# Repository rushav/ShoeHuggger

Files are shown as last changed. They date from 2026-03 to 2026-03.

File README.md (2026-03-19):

# ShoeHugger

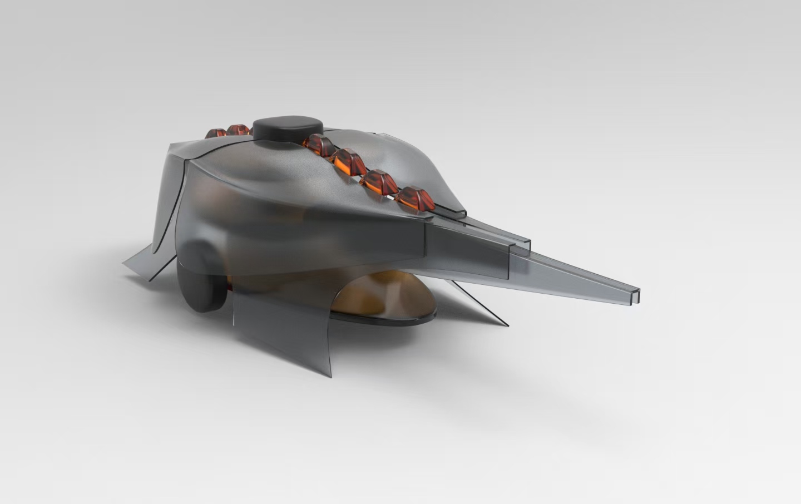
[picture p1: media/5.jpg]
ShoeHugger

More images in media folder

## About

ShoeHugger is a personal butler/pet robot built on a modified TurtleBot3 Waffle platform for TECHIN 516 at UW GIX (Winter 2025). It uses YOLOv8 pose estimation to detect and follow people by tracking ankle keypoints, features motorized wings that flap based on proximity, and avoids obstacles using LiDAR reactive avoidance.

### Demo Video
<!-- PLACEHOLDER: Add link to demo video -->
[Watch the demo video](https://youtu.be/eQ_k0fX2IQM)

## Features

- **Person Following**: Detects feet using YOLOv8n-pose ankle keypoints and follows the locked target
- **Two Modes**:
  - **Annoy Mode**: Aggressively chases person, wings flap faster as it gets closer
  - **Follow Mode**: Calmly follows from a distance, wings flap gently when stopped near person
- **Search Behavior**: Spins in place to find a new target when person is lost
- **Target Locking**: Locks onto one person's feet and ignores others using proximity + size filtering
- **Obstacle Avoidance**: Reactive LiDAR-based avoidance — slows/stops/steers around obstacles
- **Wing Mechanism**: 3rd DYNAMIXEL motor drives symmetric wings with variable-speed flapping
- **Control UI**: Tkinter GUI with mode switching, teleop, and emergency stop
- **SLAM Visualization**: Real-time map building in RViz alongside robot model
- **Auto-Start**: Pi bringup runs on boot via systemd — just power on and go

## Hardware

- TurtleBot3 Waffle (OpenCR + Raspberry Pi 4)
- 3rd DYNAMIXEL XL430 motor (ID 3) for wing mechanism
- TRAUSI 1080p USB webcam (rear-facing)
- LDS-01 LiDAR
- Custom 3D-printed chassis and wings (designed in SolidWorks)

## Team Contributions

| Member | Contributions |
|---|---|
| **Rushav** | Camera integration, person follower code (YOLO pose estimation, control logic, obstacle avoidance), custom bringup node, Pi systemd setup, UI, system integration |
| **Eason** | Robot 3D model design (SolidWorks), URDF creation and export, RViz visualization setup |
| **Phoenix** | Subscriber/publisher node architecture, ROS2 communication design |

## Architecture

```
+---------------------+     WiFi (ROS2 DDS)     +----------------------+
|   Raspberry Pi 4    |<------------------------>|   Laptop (Docker)    |
|                     |     ROS_DOMAIN_ID=117    |                      |
|alienbot_bringup.py|                          | person_follower.py   |
|  +- /cmd_vel (sub)  |                          |  +- /cmd_vel (pub)   |
|  +- /joint_states   |                          |  +- /wing_flap_speed |
|  +- /tf (odom->base)|                          |  +- /follower_image  |
|  +- /imu            |                          |                      |
|  +- /odom           |                          | alienbot_ui.py     |
|  +- /wing_flap_speed|                          | teleop_hold.py       |
|                     |                          | rviz2 + slam_toolbox |
| usb_cam_node        |                          +----------------------+
|  +- /image_raw/*    |
|                     |
| hlds_laser_publisher|
|  +- /scan           |
+---------------------+
```

## Setup Instructions

### Prerequisites
- Docker and VS Code with Dev Containers extension
- ROS2 Humble (installed in container)
- TurtleBot3 Waffle with OpenCR board flashed with GIX firmware

### 1. Clone the repository
```bash
git clone https://github.com/YOUR_USERNAME/alienbot.git
cd alienbot
```

### 2. Open in Dev Container
Open the folder in VS Code and select "Reopen in Container". The Dockerfile installs all dependencies automatically.

### 3. Build the workspace
```bash
cd ~/turtlebot4_ws
colcon build --symlink-install
source install/setup.bash
```

### 4. Set up the Raspberry Pi
Copy the Pi files and enable auto-start:
```bash
scp pi/alienbot_bringup.py ubuntu@<PI_IP>:~/alienbot_bringup.py
scp pi/start_alienbot.sh ubuntu@<PI_IP>:~/start_alienbot.sh
scp pi/alienbot.service ubuntu@<PI_IP>:~/alienbot.service
ssh ubuntu@<PI_IP>
chmod +x ~/start_alienbot.sh
sudo cp ~/alienbot.service /etc/systemd/system/
sudo systemctl daemon-reload
sudo systemctl enable alienbot
sudo systemctl start alienbot
```

Pi dependencies:
```bash
pip3 install dynamixel-sdk --break-system-packages
sudo apt install ros-humble-compressed-image-transport
```

### 5. Install OpenCR Firmware
Flash the modified GIX firmware using Arduino IDE. See `firmware/README.md` for details.

## Usage

### One-Command Launch (Laptop)
```bash
./launch/launch_alienbot.sh
```
This opens the control UI and RViz with SLAM. Use the UI buttons or keyboard shortcuts:

| Button | Key | Mode |
|---|-----|---|
| TELEOP | 1 | Manual arrow-key control |
| ANNOY | 2 | Aggressive person following + flapping |
| FOLLOW | 3 | Calm follow from distance |
| STOP ALL | 4 / Space / Esc | Emergency stop all motors |

### Manual Commands
```bash
# Test wheels
ros2 topic pub /cmd_vel geometry_msgs/msg/Twist "{linear: {x: 0.1}}" -r 10

# Test wing position
ros2 topic pub --once /wing_command std_msgs/msg/Float64 "{data: 0.5}"

# Test wing flapping
ros2 topic pub --once /wing_flap_speed std_msgs/msg/Float64 "{data: 0.5}"

# Stop flapping
ros2 topic pub --once /wing_flap_speed std_msgs/msg/Float64 "{data: 0.0}"
```

## License

This project is licensed under the Apache License 2.0 — see [LICENSE](LICENSE) for details.

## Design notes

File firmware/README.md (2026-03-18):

# OpenCR Firmware Modifications

## Overview

AlienBot uses a modified version of the GIX OpenCR firmware that adds support for a 3rd DYNAMIXEL motor (ID 3) used to drive the wing mechanism.

## Source Repository

The firmware is based on the `t516_OpenCR` repository provided for TECHIN 516.

## Configuration

In `t516_OpenCR.ino`, select the robot model:
```cpp
#define MODEL GIX_Waffle
```

## Key Modifications

### Velocity Limit
- `LIMIT_X_MAX_VELOCITY` increased from **337** to **500** to allow faster driving

### Wheel Separation
- Modified from **0.287 m** to **0.1552 m** to match the actual wheel-to-wheel distance of the custom chassis

### GIX Motor Driver (Wing Motor — DYNAMIXEL ID 3)
The GIX motor driver firmware extension reads and writes to DYNAMIXEL ID 3 using these control table addresses:

| Address | Description |
|---|---|
| 346 | Wing command input |
| 348-382 | Motor control registers |

The wing motor accepts:
- **Position commands** via `/wing_command` (Float64, 0.0–1.0 normalized)
- **Flap speed commands** via `/wing_flap_speed` (Float64, 0.0–1.0; 0.0 = stop flapping)

The bringup node on the Pi translates these ROS topics into DYNAMIXEL SDK writes.

## Flashing

1. Open `t516_OpenCR.ino` in Arduino IDE
2. Select board: **OpenCR**
3. Connect OpenCR via USB
4. Upload firmware
5. Verify by checking that all three motors respond (IDs 1, 2, 3)

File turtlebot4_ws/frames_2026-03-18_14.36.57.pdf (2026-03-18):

view_frames Result

Recorded at time: 1773869817.2450194

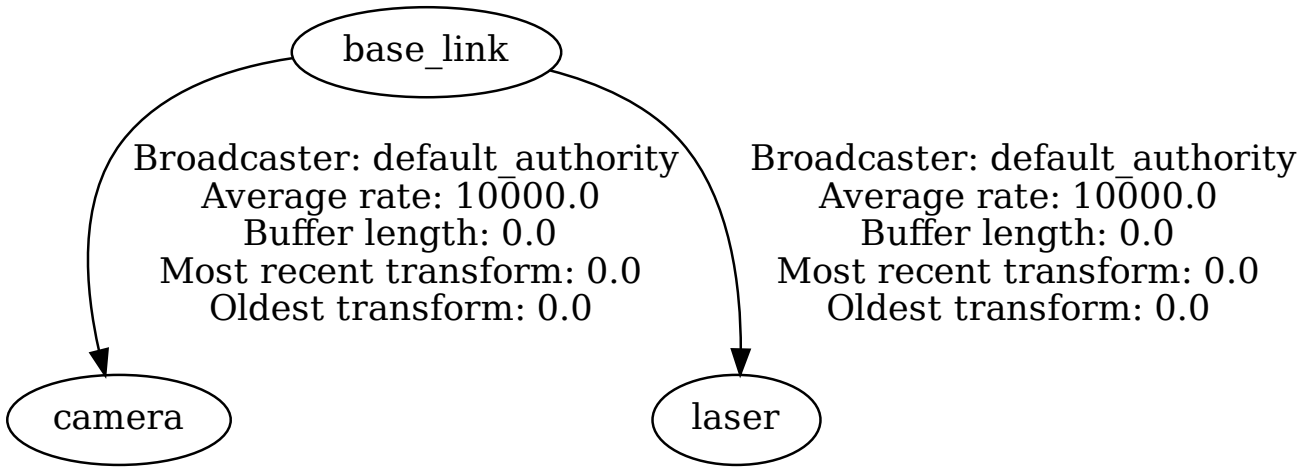
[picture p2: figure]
base_link; camera; Broadcaster: default_authority Average rate: 10000.0 Buffer length: 0.0 Most recent transform: 0.0 Oldest transform: 0.0; laser

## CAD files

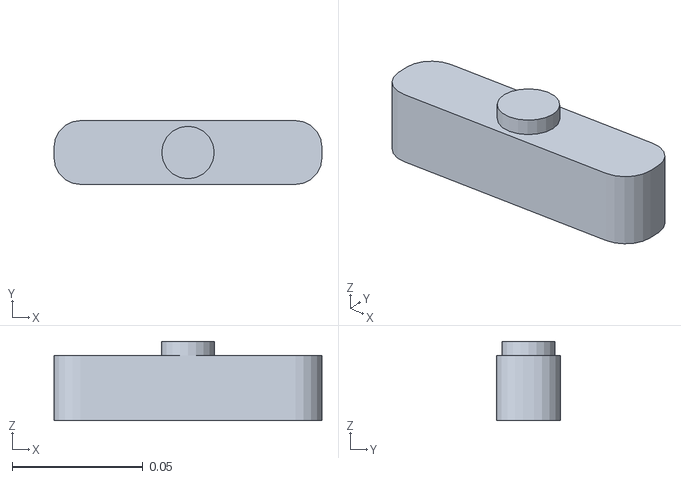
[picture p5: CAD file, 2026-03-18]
description/stls/camera.STL
0.103 x 0.0244 x 0.0302

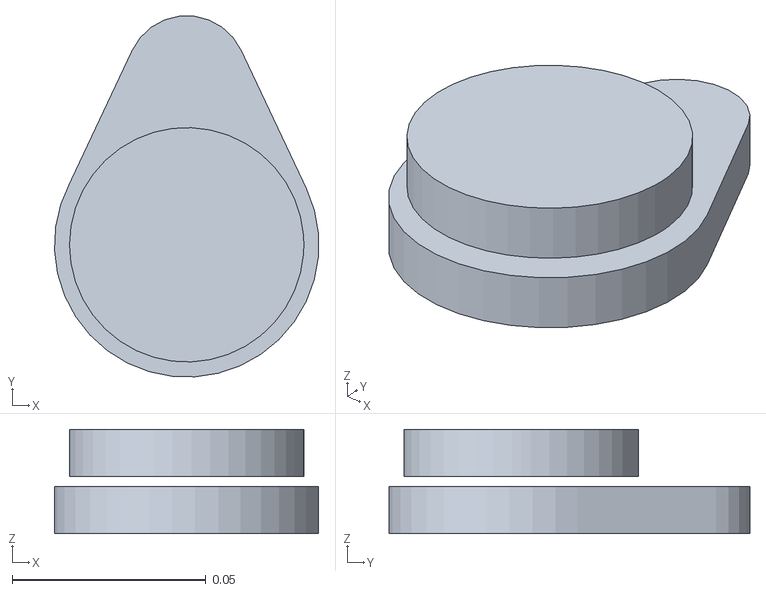
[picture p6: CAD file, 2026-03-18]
turtlebot4_ws/src/alienbot_description/stls/lidar.STL
0.068 x 0.093 x 0.0269

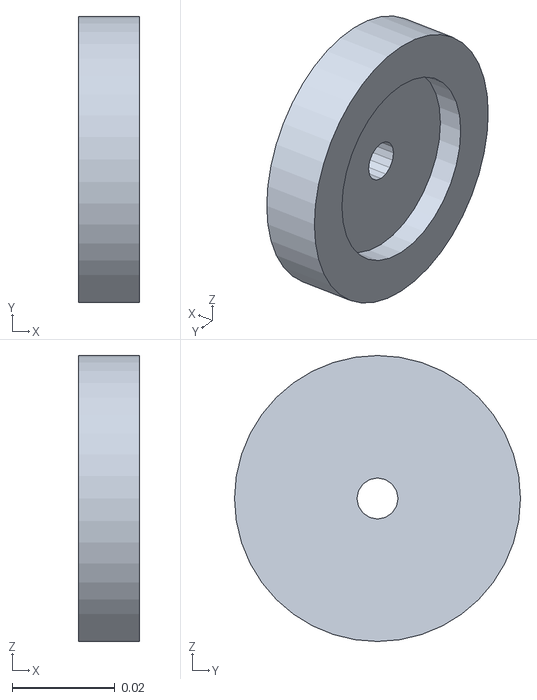
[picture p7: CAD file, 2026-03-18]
description/stls/wheel_right.STL
0.0119 x 0.0558 x 0.0558

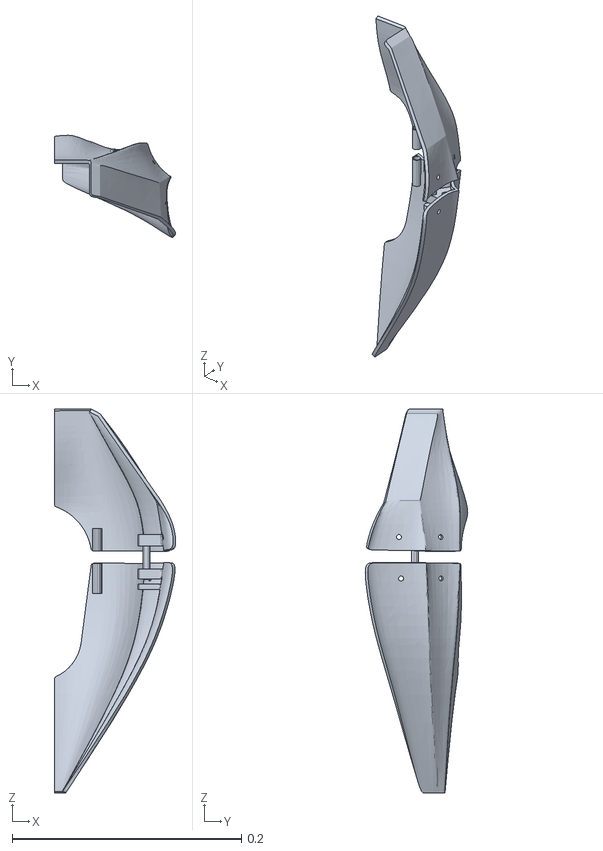
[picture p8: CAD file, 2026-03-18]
turtlebot4_ws/src/alienbot_description/stls/wing_left.STL
0.106 x 0.0894 x 0.335

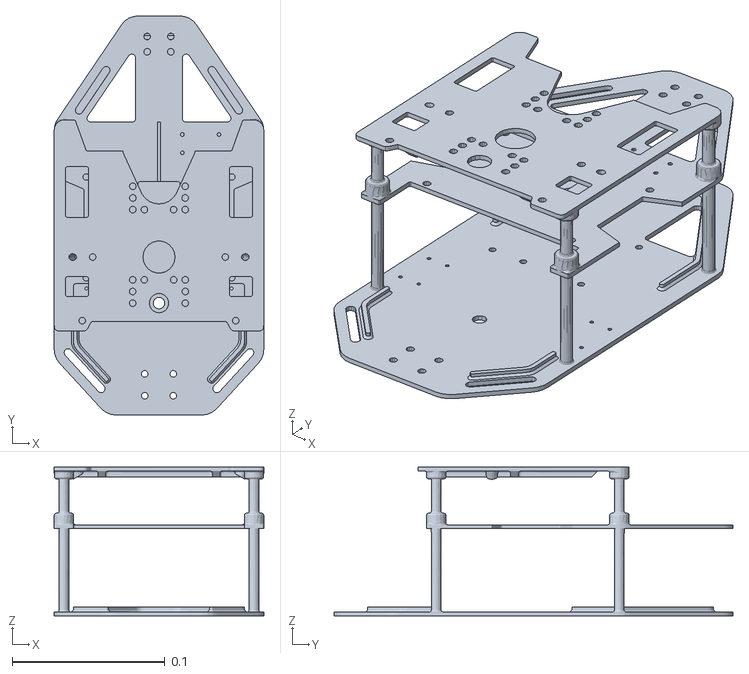
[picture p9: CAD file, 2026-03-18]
description/stls/base_link.STL
0.137 x 0.261 x 0.0972

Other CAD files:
description/stls/wing_right.STL
description/stls/wheel_left.STL
turtlebot4_ws/src/alienbot_description/stls/wheel_left.STL
turtlebot4_ws/src/alienbot_description/stls/wing_right.STL

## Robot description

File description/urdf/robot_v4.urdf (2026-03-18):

<?xml version="1.0" encoding="utf-8"?>
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
<robot name="robot_v4">
  <link name="base_link">
    <inertial>
      <origin xyz="5.19808910696973E-06 0.0437851037954019 -0.0153253924126023" rpy="0 0 0" />
      <mass value="0.174534133721049" />
      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
    </inertial>
    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
  </link>
  <link name="wheel_left">
    <inertial>
      <origin xyz="0.00514407681200836 8.17349660175992E-14 3.4527242176452E-13" rpy="0 0 0" />
      <mass value="0.0230128273536347" />
      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
    </inertial>
    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
  </link>
  <joint name="wheel_left_joint" type="continuous">
    <origin xyz="0.0725550532863032 0.0249218786292363 -0.0402038669112" rpy="1.5707963267949 0 0" />
    <parent link="base_link" />
    <child link="wheel_left" />
    <axis xyz="1 0 0" />
  </joint>
  <link name="wheel_right">
    <inertial>
      <origin xyz="-0.00514407681092399 -1.85615411929518E-16 -5.59760571228196E-14" rpy="0 0 0" />
      <mass value="0.0230128273536347" />
      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
    </inertial>
    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
  </link>
  <joint name="wheel_right_joint" type="continuous">
    <origin xyz="-0.0725550532790476 0.0249218786307316 -0.0402038669083703" rpy="1.5707963267949 0 0" />
    <parent link="base_link" />
    <child link="wheel_right" />
    <axis xyz="1 0 0" />
  </joint>
  <link name="laser">
    <inertial>
      <origin xyz="1.12248706154588E-05 0.0070553880342903 -0.000411928460549202" rpy="0 0 0" />
      <mass value="0.0906117336671421" />
      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
    </inertial>
    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
  </link>
  <joint name="laser_joint" type="fixed">
    <origin xyz="0 0.0155312690459461 0.055853305909985" rpy="0 0 0" />
    <parent link="base_link" />
    <child link="laser" />
    <axis xyz="0 0 0" />
  </joint>
  <link name="camera">
    <inertial>
      <origin xyz="3.46944695195361E-17 -0.000483315503227374 -0.0120319760925751" rpy="0 0 0" />
      <mass value="0.0618368133993102" />
      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
    </inertial>
    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
  </link>
  <joint name="camera_joint" type="fixed">
    <origin xyz="0 -0.102735934689195 0.0173275485336867" rpy="1.5707963267949 0 0" />
    <parent link="base_link" />
    <child link="camera" />
    <axis xyz="0 0 0" />
  </joint>
  <link name="wing_left">
    <inertial>
      <origin xyz="0.0202267783404892 -0.0171927414394959 -0.0447062400052274" rpy="0 0 0" />
      <mass value="0.11060024558919" />
      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
    </inertial>
    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
  </link>
  <joint name="wing_left_joint" type="continuous">
    <origin xyz="0.051772 0 0.048599" rpy="1.5708 0 0" />
    <parent link="base_link" />
    <child link="wing_left" />
    <axis xyz="0 0 1" />
  </joint>
  <link name="wing_right">
    <inertial>
      <origin xyz="-0.0202320893781205 -0.0171966751818292 -0.044652227528606" rpy="0 0 0" />
      <mass value="0.110625066259541" />
      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
    </inertial>
    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
  </link>
  <joint name="wing_right_joint" type="continuous">
    <origin xyz="-0.051772 0 0.048599" rpy="1.5708 0 0" />
    <parent link="base_link" />
    <child link="wing_right" />
    <axis xyz="0 0 1" />
  </joint>
</robot>

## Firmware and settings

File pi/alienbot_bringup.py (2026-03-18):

#!/usr/bin/env python3
"""
AlienBot Bringup Node — Raspberry Pi
=====================================
Custom replacement for turtlebot3_node that runs on the Raspberry Pi.
Communicates with the OpenCR board via DynamixelSDK to control:
  - Wheel motors (DYNAMIXEL ID 1, ID 2)
  - Wing motor (DYNAMIXEL ID 3)

Publishes:
    /odom (nav_msgs/Odometry) — wheel odometry
    /tf (odom → base_link transform)
    /imu (sensor_msgs/Imu) — IMU data from OpenCR
    /joint_states (sensor_msgs/JointState) — wheel + wing joint positions

Subscribes:
    /cmd_vel (geometry_msgs/Twist) — velocity commands for wheels
    /wing_flap_speed (std_msgs/Float64) — wing flap speed (0.0–1.0)
    /wing_command (std_msgs/Float64) — direct wing position (0.0–1.0)

This node reads motor positions and IMU data from OpenCR at ~30 Hz,
computes odometry, and publishes all sensor data to ROS2 topics.

Requires:
    pip3 install dynamixel-sdk

Usage:
    python3 alienbot_bringup.py
    OR via systemd (see alienbot.service)
"""

import math
import signal
import struct
import sys
import threading
import time

import rclpy
from rclpy.node import Node
from rclpy.qos import QoSProfile, ReliabilityPolicy
from geometry_msgs.msg import Twist, TransformStamped, Quaternion
from nav_msgs.msg import Odometry
from sensor_msgs.msg import Imu, JointState
from std_msgs.msg import Float64
from tf2_ros import TransformBroadcaster

from dynamixel_sdk import PortHandler, PacketHandler

# ── Hardware Configuration ────────────────────────────────────────────────────
DEVICE_PORT       = '/dev/ttyACM0'
BAUDRATE          = 1000000
PROTOCOL_VERSION  = 2.0

# DYNAMIXEL motor IDs
MOTOR_ID_LEFT     = 1    # left wheel
MOTOR_ID_RIGHT    = 2    # right wheel
MOTOR_ID_WING     = 3    # wing mechanism

# Robot physical parameters
WHEEL_RADIUS      = 0.033   # meters
WHEEL_SEPARATION  = 0.1552  # meters (modified from stock 0.287)

# OpenCR control table addresses for reading sensor data
ADDR_PRESENT_POSITION = 132   # 4 bytes
ADDR_PRESENT_VELOCITY = 128   # 4 bytes

# Wing motor control
ADDR_GOAL_POSITION    = 116   # 4 bytes
WING_MIN_POS          = 1024  # ~90° range of motion
WING_MAX_POS          = 3072
WING_CENTER_POS       = 2048

# GIX motor driver addresses for wing via OpenCR
ADDR_GIX_WING_CMD     = 346  # wing command register

# ── Timing ────────────────────────────────────────────────────────────────────
CONTROL_RATE_HZ   = 30    # main control loop frequency
CMD_VEL_TIMEOUT   = 1.0   # seconds — stop if no cmd_vel received
# ─────────────────────────────────────────────────────────────────────────────


class AlienBotBringup(Node):
    """ROS2 bringup node for AlienBot hardware on Raspberry Pi."""

    def __init__(self) -> None:
        super().__init__('alienbot_bringup')

        # ── DynamixelSDK setup ────────────────────────────────────────────
        self.port_handler = PortHandler(DEVICE_PORT)
        self.packet_handler = PacketHandler(PROTOCOL_VERSION)

        if not self.port_handler.openPort():
            self.get_logger().fatal(f'Failed to open port {DEVICE_PORT}')
            sys.exit(1)
        if not self.port_handler.setBaudRate(BAUDRATE):
            self.get_logger().fatal(f'Failed to set baudrate {BAUDRATE}')
            sys.exit(1)

        self.get_logger().info(
            f'Connected to OpenCR on {DEVICE_PORT} at {BAUDRATE} baud')

        # ── Publishers ────────────────────────────────────────────────────
        self.odom_pub = self.create_publisher(Odometry, '/odom', 10)
        self.imu_pub = self.create_publisher(Imu, '/imu', 10)
        self.joint_pub = self.create_publisher(JointState, '/joint_states', 10)
        self.tf_broadcaster = TransformBroadcaster(self)

        # ── Subscribers ───────────────────────────────────────────────────
        self.cmd_vel_sub = self.create_subscription(
            Twist, '/cmd_vel', self.cmd_vel_callback, 10)
        self.wing_flap_sub = self.create_subscription(
            Float64, '/wing_flap_speed', self.wing_flap_callback, 10)
        self.wing_cmd_sub = self.create_subscription(
            Float64, '/wing_command', self.wing_cmd_callback, 10)

        # ── State ─────────────────────────────────────────────────────────
        self.target_linear = 0.0
        self.target_angular = 0.0
        self.last_cmd_time = time.time()

        # Odometry state
        self.odom_x = 0.0
        self.odom_y = 0.0
        self.odom_theta = 0.0
        self.prev_left_pos = None
        self.prev_right_pos = None
        self.prev_time = time.time()

        # Wing flap state
        self.wing_flap_speed = 0.0
        self.wing_flap_phase = 0.0
        self.wing_position = 0.5  # normalized 0.0–1.0

        self.running = True

        # ── Main control timer ────────────────────────────────────────────
        self.control_timer = self.create_timer(
            1.0 / CONTROL_RATE_HZ, self.control_loop)

        self.get_logger().info('AlienBot bringup node started!')

    # ── Callbacks ─────────────────────────────────────────────────────────

    def cmd_vel_callback(self, msg: Twist) -> None:
        """Receive velocity commands for wheels."""
        self.target_linear = msg.linear.x
        self.target_angular = msg.angular.z
        self.last_cmd_time = time.time()

    def wing_flap_callback(self, msg: Float64) -> None:
        """Set wing flap speed (0.0 = stop, 1.0 = max speed)."""
        self.wing_flap_speed = max(0.0, min(1.0, msg.data))
        if self.wing_flap_speed == 0.0:
            self.wing_flap_phase = 0.0
        self.get_logger().info(f'Wing flap speed: {self.wing_flap_speed:.2f}')

    def wing_cmd_callback(self, msg: Float64) -> None:
        """Set wing position directly (0.0–1.0 normalized)."""
        self.wing_position = max(0.0, min(1.0, msg.data))
        self.wing_flap_speed = 0.0  # direct position overrides flapping

    # ── Main control loop ─────────────────────────────────────────────────

    def control_loop(self) -> None:
        """Read sensors, compute odometry, send motor commands at fixed rate."""
        if not self.running:
            return

        now = time.time()
        dt = now - self.prev_time
        self.prev_time = now

        # Watchdog — stop if no cmd_vel received recently
        if now - self.last_cmd_time > CMD_VEL_TIMEOUT:
            self.target_linear = 0.0
            self.target_angular = 0.0

        # Send wheel velocity commands
        self._send_wheel_velocities(self.target_linear, self.target_angular)

        # Update wing flapping
        self._update_wing(dt)

        # Publish odometry and TF
        self._publish_odometry(dt)

        # Publish joint states
        self._publish_joint_states()

    # ── Motor control ─────────────────────────────────────────────────────

    def _send_wheel_velocities(self, linear: float, angular: float) -> None:
        """Convert (linear, angular) to individual wheel velocities and send."""
        left_vel = linear - angular * WHEEL_SEPARATION / 2.0
        right_vel = linear + angular * WHEEL_SEPARATION / 2.0

        # Convert m/s to DYNAMIXEL velocity units
        left_raw = int(left_vel / (WHEEL_RADIUS * 2 * math.pi) * 60 / 0.229)
        right_raw = int(right_vel / (WHEEL_RADIUS * 2 * math.pi) * 60 / 0.229)

        try:
            self.packet_handler.write4ByteTxOnly(
                self.port_handler, MOTOR_ID_LEFT, ADDR_PRESENT_VELOCITY, left_raw)
            self.packet_handler.write4ByteTxOnly(
                self.port_handler, MOTOR_ID_RIGHT, ADDR_PRESENT_VELOCITY, right_raw)
        except Exception as e:
            self.get_logger().warning(f'Wheel write error: {e}')

    def _update_wing(self, dt: float) -> None:
        """Update wing position based on flap speed or direct command."""
        if self.wing_flap_speed > 0.0:
            # Sinusoidal flapping
            freq = self.wing_flap_speed * 3.0  # max ~3 Hz flap
            self.wing_flap_phase += freq * dt * 2 * math.pi
            position = 0.5 + 0.4 * math.sin(self.wing_flap_phase)
        else:
            position = self.wing_position

        # Convert to DYNAMIXEL position
        goal_pos = int(WING_MIN_POS + position * (WING_MAX_POS - WING_MIN_POS))
        try:
            self.packet_handler.write4ByteTxOnly(
                self.port_handler, MOTOR_ID_WING, ADDR_GOAL_POSITION, goal_pos)
        except Exception as e:
            self.get_logger().warning(f'Wing write error: {e}')

    # ── Odometry ──────────────────────────────────────────────────────────

    def _publish_odometry(self, dt: float) -> None:
        """Compute and publish wheel odometry + TF."""
        stamp = self.get_clock().now().to_msg()

        # Publish odometry message
        odom_msg = Odometry()
        odom_msg.header.stamp = stamp
        odom_msg.header.frame_id = 'odom'
        odom_msg.child_frame_id = 'base_link'
        odom_msg.pose.pose.position.x = self.odom_x
        odom_msg.pose.pose.position.y = self.odom_y
        odom_msg.pose.pose.orientation = self._yaw_to_quaternion(self.odom_theta)
        odom_msg.twist.twist.linear.x = self.target_linear
        odom_msg.twist.twist.angular.z = self.target_angular
        self.odom_pub.publish(odom_msg)

        # Broadcast TF: odom → base_link
        tf_msg = TransformStamped()
        tf_msg.header.stamp = stamp
        tf_msg.header.frame_id = 'odom'
        tf_msg.child_frame_id = 'base_link'
        tf_msg.transform.translation.x = self.odom_x
        tf_msg.transform.translation.y = self.odom_y
        q = self._yaw_to_quaternion(self.odom_theta)
        tf_msg.transform.rotation = q
        self.tf_broadcaster.sendTransform(tf_msg)

    def _publish_joint_states(self) -> None:
        """Publish joint states for URDF visualization."""
        js = JointState()
        js.header.stamp = self.get_clock().now().to_msg()
        js.name = ['wheel_left_joint', 'wheel_right_joint',
                    'wing_left_joint', 'wing_right_joint']
        js.position = [0.0, 0.0, 0.0, 0.0]
        js.velocity = []
        js.effort = []
        self.joint_pub.publish(js)

    @staticmethod
    def _yaw_to_quaternion(yaw: float) -> Quaternion:
        """Convert a yaw angle to a Quaternion message."""
        q = Quaternion()
        q.x = 0.0
        q.y = 0.0
        q.z = math.sin(yaw / 2.0)
        q.w = math.cos(yaw / 2.0)
        return q

    # ── Shutdown ──────────────────────────────────────────────────────────

    def shutdown(self) -> None:
        """Stop all motors and close port."""
        self.running = False
        self.get_logger().info('Shutting down — stopping all motors...')
        try:
            # Stop wheels
            self.packet_handler.write4ByteTxOnly(
                self.port_handler, MOTOR_ID_LEFT, ADDR_PRESENT_VELOCITY, 0)
            self.packet_handler.write4ByteTxOnly(
                self.port_handler, MOTOR_ID_RIGHT, ADDR_PRESENT_VELOCITY, 0)
            # Center wings
            self.packet_handler.write4ByteTxOnly(
                self.port_handler, MOTOR_ID_WING, ADDR_GOAL_POSITION, WING_CENTER_POS)
        except Exception:
            pass
        self.port_handler.closePort()


def main(args=None):
    rclpy.init(args=args)
    node = AlienBotBringup()

    def signal_handler(sig, frame):
        node.get_logger().info(f'Signal {sig} received — shutting down.')
        node.shutdown()
        try:
            rclpy.shutdown()
        except Exception:
            pass

    signal.signal(signal.SIGTERM, signal_handler)
    signal.signal(signal.SIGINT, signal_handler)

    try:
        rclpy.spin(node)
    except KeyboardInterrupt:
        pass
    finally:
        node.shutdown()
        try:
            node.destroy_node()
            rclpy.shutdown()
        except Exception:
            pass


if __name__ == '__main__':
    main()

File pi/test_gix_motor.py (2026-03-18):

#!/usr/bin/env python3
"""
GIX Motor Test Utility
=======================
Simple test script for verifying DYNAMIXEL motor communication via OpenCR.
Tests wheel motors (ID 1, 2) and wing motor (ID 3) individually.

Usage:
    python3 test_gix_motor.py

Requires:
    pip3 install dynamixel-sdk
"""

import sys
import time

from dynamixel_sdk import PortHandler, PacketHandler

# Configuration
DEVICE_PORT      = '/dev/ttyACM0'
BAUDRATE         = 1000000
PROTOCOL_VERSION = 2.0

# Motor IDs
MOTOR_LEFT  = 1
MOTOR_RIGHT = 2
MOTOR_WING  = 3

# Control table addresses
ADDR_TORQUE_ENABLE    = 64
ADDR_GOAL_POSITION    = 116
ADDR_PRESENT_POSITION = 132
ADDR_GOAL_VELOCITY    = 104

TORQUE_ENABLE  = 1
TORQUE_DISABLE = 0


def main():
    port = PortHandler(DEVICE_PORT)
    pkt = PacketHandler(PROTOCOL_VERSION)

    if not port.openPort():
        print(f'ERROR: Cannot open {DEVICE_PORT}')
        sys.exit(1)
    if not port.setBaudRate(BAUDRATE):
        print(f'ERROR: Cannot set baudrate {BAUDRATE}')
        sys.exit(1)

    print(f'Connected to {DEVICE_PORT} at {BAUDRATE} baud')
    print()

    # Ping all motors
    for motor_id, name in [(MOTOR_LEFT, 'Left Wheel'),
                            (MOTOR_RIGHT, 'Right Wheel'),
                            (MOTOR_WING, 'Wing')]:
        model, result, error = pkt.ping(port, motor_id)
        if result == 0:
            print(f'  Motor {motor_id} ({name}): OK (model: {model})')
        else:
            print(f'  Motor {motor_id} ({name}): NOT FOUND')

    print()
    input('Press Enter to test wing motor (ID 3)...')

    # Enable wing motor torque
    pkt.write1ByteTxRx(port, MOTOR_WING, ADDR_TORQUE_ENABLE, TORQUE_ENABLE)

    # Move wing to a few positions
    positions = [1500, 2048, 2500, 2048]
    for pos in positions:
        print(f'  Moving wing to position {pos}...')
        pkt.write4ByteTxRx(port, MOTOR_WING, ADDR_GOAL_POSITION, pos)
        time.sleep(1.0)

        curr_pos, _, _ = pkt.read4ByteTxRx(port, MOTOR_WING, ADDR_PRESENT_POSITION)
        print(f'  Current position: {curr_pos}')

    # Disable torque
    pkt.write1ByteTxRx(port, MOTOR_WING, ADDR_TORQUE_ENABLE, TORQUE_DISABLE)
    print()
    print('Wing motor test complete.')

    port.closePort()


if __name__ == '__main__':
    main()
